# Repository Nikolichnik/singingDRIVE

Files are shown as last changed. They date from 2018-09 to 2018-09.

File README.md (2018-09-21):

# singingDRIVE
<h4>Old CD-ROM drive re purposed to sing.</h4>

It includes stepper motor driver controlled by Arduino microntroller. Video demo available <a href="https://www.youtube.com/watch?v=EQ7sJ51bUXY"><em>here</em></a> or you can just click image below.

<hr>

<p align="center">
  
</p>

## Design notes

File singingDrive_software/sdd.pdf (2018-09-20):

/*
----------------------------------------------------------------------------------------------------------------------------Ima gomila stimunga koji treba tek da se klasifikuje i upakuje kako treba- bude li potrebe. :P
Definisane vrednosti za note su cesto tweakovane da bi se postigao neki efekat u nekim deonicama- ima
dosta odstupanja od zadatih vrednosti. Osnova za navedene zadate vrednosti je u tabeli ispod:

vr. note I vr. u f-ji
cela | I | 4
pola | I | 2
cetvrtinaI | 1
osmina I | 0.5
1/16 | I | 0.25
1/32 | I | 0.125
1/64 | I | 0.0625

----------------------------------------------------------------------------------------------------------------------------*/

int coila1 = 4;
int coila2 = 5;
int coilb1 = 6;
int coilb2 = 7;
int sensor = 11;

int LEDb = 13;
int LEDc = 10;
float tempo = 99.00; | // Tempo, bpm.
float t = (60.00/tempo)/8; | // Trajanje cele note u sekundama/8
int o = 1; // Za podizanje oktave.
float H0 = o*30.87;
float C1 = o*32.70;
float C1s = o*34.65;
float D1 = o*36.71;
float D1s = o*38.89;
float E1 = o*41.20;
float F1 = o*43.65;
float F1s = o*46.25;
float G1 = o*49.00;
float G1s = o*51.91;
float lA1 = o*55.00; | // Zbog postojeih promenljivih za analogne pinove.
float A1s = o*58.27;
float H1 = o*61.74;
float C2 = o*65.41;
float C2s = o*69.30;
float D2 = o*73.42;
float D2s = o*77.80;
float E2 = o*82.41;
float F2 = o*87.31;
float F2s = o*92.50;
float G2 = o*98.00;
float G2s = o*103.83;
float lA2 = o*110.00; | // Zbog postojeih promenljivih za analogne pinove.
float A2s = o*116.54;
float H2 = o*123.47;
float C3 = o*130.81;
float C3s = o*138.59;
float D3 = o*146.83;
float D3s = o*155.56;
float E3 = o*164.81;
float F3 = o*179.61;
float F3s = o*185.00;
float G3 = o*199.9999;
float G3s = o*207.65;
float lA3 = o*220.00; | // Zbog postojeih promenljivih za analogne pinove.
float A3s = o*233.08;
float H3 = o*246.94;
float C4 = o*261.63;

void setup() {

pinMode(coila1, OUTPUT);
pinMode(coila2, OUTPUT);
pinMode(coilb1, OUTPUT);
pinMode(coilb2, OUTPUT);
pinMode(sensor, INPUT);
pinMode(LEDb, OUTPUT);
pinMode(LEDc, OUTPUT);

Serial.begin(115200);

}

void loop() {

float cela = 4;
float pola = 2;
float cetvrtina = 1;
float osmina = 0.5;
float sesnaestina = 0.25;
float tripola = 0.125;
float sestcetvrt = 0.0625;
float dvanaestosam = 0.03125;
float p = (t*1000.0)/8; | // Vrednost cele pauze, t je trajanje cele note u sekundama/8, za delay funkciju nam trebaju milisekunde.
int sensor_state;

sensor_state = digitalRead(sensor);

if(sensor_state == LOW) { | // Kako bismo vratili šeta✁a na po✁etak pre svake ponovljene sekvence.

play(C4, 0.01, 0);

}

else {

//-----------------------------------------------------------------------------------------------------------------------------------------------------------------------

delay(900);

play(C3, 1, 1);
delay(p*0.75);
play(C3, 0.5, 1);
play(C3, 0.165, 1);
play(C3, 0.165, 0);
play(C3, 0.165, 1);
play(C3, 0.5, 0);
play(C3, 0.165, 0);
play(C3, 0.165, 1);
play(C3, 0.165, 0);
play(G2s, 0.165, 1);
play(G2s, 0.165, 0);
play(G2s, 0.165, 1);
play(G2s, 0.5, 1);
delay(p);

play(C3, 1, 1);
delay(p*0.75);
play(C3, 0.5, 1);
play(C3, 0.165, 1);
play(C3, 0.165, 0);
play(C3, 0.165, 1);
play(C3, 0.5, 0);
play(C3, 0.165, 0);
play(C3, 0.165, 0);
play(C3, 0.165, 0);
play(G2s, 0.165, 1);
play(G2s, 0.165, 0);
play(G2s, 0.165, 1);
play(G2s, 0.5, 1);
delay(p);

play(C3, 1, 1);
delay(p*0.75);
play(C3, 0.5, 0);
play(C3, 0.165, 1);
play(C3, 0.165, 0);
play(C3, 0.165, 1);
play(C3, 0.5, 0);
play(C3, 0.165, 0);
play(C3, 0.165, 0);
play(C3, 0.165, 0);
play(G2s, 0.165, 1);
play(G2s, 0.165, 1);
play(G2s, 0.165, 1);
play(G2s, 0.5, 1);
delay(p);

play(C2, 1.1, 0);
play(C2, 1.1, 0);
play(C2, 1.1, 0);
play(G1s, 0.75, 1);
play(D2s, 0.33, 0);
play(C2, 1.1, 1);
play(G1s, 0.75, 1);
play(D2s, 0.33, 0);
play(C2, 2, 0);
play(G2, 1.1, 0);
play(G2, 1.1, 1);
play(G2, 1.1, 0);
play(G2s, 0.75, 1);
play(D2s, 0.33, 0);
play(C2, 1.1, 1);
play(G1s, 0.75, 1);
play(D2s, 0.33, 0);
play(C2, 2, 0);

play(C3, 1.1, 1);
play(C2, 0.75, 0);
play(C2, 0.25, 1);
play(C3, 1.1, 1);
play(H2, 0.75, 0);
play(A2s, 0.25, 1);
play(lA2, 0.25, 0);
play(G2s, 0.25, 1);
play(lA2, 0.5, 0);
delay(p*32);
play(C2s, 0.45, 1);
delay(p*0.25);
play(F2s, 1.1, 0);
play(F2, 0.75, 1);
play(E2, 0.25, 0);
play(D2s, 0.25, 1);
play(D2, 0.25, 0);
play(D2s, 0.5, 1);
delay(p*32);
play(G1s, 0.45, 1);
play(H1, 1.1, 1);
play(G1s, 0.75, 1);
delay(p*0.25);
play(H1, 0.25, 0);
play(D2s, 1.1, 0);
play(C2, 0.75, 1);
delay(p*0.25);
play(D2s, 0.25, 0);
play(G2, 2.2, 0);

play(C3, 1.1, 1);
play(C2, 0.75, 0);
play(C2, 0.25, 1);
play(C3, 1.1, 1);
play(H2, 0.75, 0);
play(A2s, 0.25, 1);
play(lA2, 0.25, 0);
play(G2s, 0.25, 1);
play(lA2, 0.5, 0);
delay(p*32);
play(C2s, 0.45, 1);

play(F2s, 1.1, 0);
play(F2, 0.75, 1);
play(E2, 0.25, 0);

play(D2s, 0.25, 1);
play(D2, 0.25, 0);
play(D2s, 0.5, 1);
delay(p*32);
play(G1s, 0.45, 1);
play(H1, 1.1, 1);
play(G1s, 0.75, 1);

play(H1, 0.25, 0);
play(D2s, 1.1, 0);
play(G1s, 0.75, 1);
delay(p*0.25);
play(C2, 0.25, 0);
play(C2, 2.5, 0);
delay(p*0.5);

play(C3, 1, 1);
delay(p*0.5);
play(C3, 0.5, 1);
play(C3, 0.165, 1);
play(C3, 0.165, 0);
play(C3, 0.165, 1);
play(C3, 0.5, 0);
play(C3, 0.165, 0);
play(C3, 0.165, 1);
play(C3, 0.165, 0);
play(G2s, 0.165, 1);
play(G2s, 0.165, 0);
play(G2s, 0.165, 1);
play(G2s, 0.5, 1);
delay(p);

play(C3, 1, 1);
delay(p*0.75);
play(C3, 0.5, 1);
play(C3, 0.165, 1);
play(C3, 0.165, 0);
play(C3, 0.165, 1);
play(C3, 0.5, 0);
play(C3, 0.165, 0);
play(C3, 0.165, 1);
play(C3, 0.165, 0);
play(G2s, 0.165, 1);
play(G2s, 0.165, 0);
play(G2s, 0.165, 1);
play(G2s, 0.5, 1);
delay(p);

play(C3, 1, 1);
delay(p*0.75);
play(C3, 0.5, 1);
play(C3, 0.165, 0);
play(C3, 0.165, 0);
play(C3, 0.165, 1);
play(C3, 0.5, 0);
play(C3, 0.165, 0);
play(C3, 0.165, 1);
play(C3, 0.165, 0);
play(G2s, 0.165, 1);
play(G2s, 0.165, 0);
play(G2s, 0.165, 1);
play(G2s, 0.5, 0);

play(G2, 0.5, 0);
play(G2, 0.165, 0);
play(G2, 0.165, 0);
play(G2, 0.165, 0);

play(G2s, 0.165, 0);
play(G2s, 0.165, 0);
play(G2s, 0.165, 0);
play(A2s, 0.5, 0);

play(C3, 0.5, 0);
play(C3, 0.165, 0);
play(C3, 0.165, 0);
play(C3, 0.165, 0);
play(C3s, 0.165, 1);
play(C3s, 0.165, 0);
play(C3s, 0.165, 1);
play(F3, 0.5, 0);

delay(p*256);

/*
play(D2, 2.2, 1);
delay(p*2.2);
play(D2, 2.2, 1);
delay(p*2.2);
play(D2, 2.2, 1);
delay(p*2.2);
play(D2, 2.2, 1);
delay(p*2.2);
play(D2, 2.2, 0);
delay(p*2.2);
play(D2, 2.2, 0);
delay(p*2.2);
play(D2, 2.2, 0);
delay(p*2.2);
play(D2, 2.2, 0);
delay(p*2.2);
*/
//------------------------------------------------------------------------------------------------------------------------------------------------------------------

play(C2, 1.5, 1);
play(C2, 0.25, 1);

play(C2, 1.5, 1);

play(C2, 1, 1);
play(C2, 1, 1);
play(C2, 0.5, 0);

play(C2, 0.33, 0);
play(C2, 0.33, 1);
play(C2, 0.33, 0);

play(E2, 1.5, 1);

play(E2, 1.5, 0);

play(C2, 0.25, 0);
play(E2, 1, 1);
play(E2, 1, 0);
play(E2, 0.5, 1);
play(E2, 0.5, 0);
play(E2, 0.33, 1);
play(C2, 0.33, 0);
play(E2, 0.33, 1);

play(G2, 1.5, 1);
play(E2, 0.25, 1);
play(E2, 0.25, 0);
play(G2, 1.5, 0);
play(E2, 0.25, 1);
play(E2, 0.25, 0);
play(G2, 1, 1);
play(G2, 1, 0);
play(G2, 0.5, 1);
play(G2, 0.5, 0);
play(G2, 0.33, 1);
play(E2, 0.33, 0);
play(G2, 0.33, 1);

play(lA2, 2.5, 0);
delay(p*0.5);
play(lA2, 0.33, 1);
play(lA2, 0.33, 0);
play(lA2, 0.33, 1);
play(H2, 1.5, 1);
play(C3, 0.1875, 0);
play(H3, 0.1875, 0);
play(lA3, 0.1875, 0);
play(G3, 0.1875, 0);
play(C3, 0.1875, 1);
play(H3, 0.1875, 1);
play(lA3, 0.1875, 1);
play(G3, 0.1875, 1);
play(C3, 1, 0);
play(C3, 0.33, 1);
play(C3, 0.33, 0);
play(C3, 0.33, 1);
play(C3, 0.5, 0);
delay(p*32);

play(C2, 0.75, 1);
play(C2, 0.25, 1);
play(F2, 2, 1);
play(G2, 1.35, 1);
play(G2s, 0.33, 0);
play(A2s, 0.33, 1);
play(G2s, 2, 0);
play(C2, 1.1, 1);
delay(p*0.5);

play(C2, 0.5, 1);
play(C2, 0.5, 0);
play(F2, 1.7, 1);
play(G2, 0.5, 1);
play(G2s, 0.5, 0);
play(C2, 0.5, 1);
play(lA2, 0.33, 0);
play(F2, 0.33, 1);
play(C3, 0.33, 0);
play(A2s, 3, 0);

play(C2, 0.75, 1);
play(C2, 0.25, 1);
play(F2, 1.75, 0);
play(G2, 0.25, 1);
play(G2s, 0.75, 1);
play(F2, 0.25, 1);
play(C3, 0.75, 1);
play(lA2, 0.25, 1);
play(F3, 2, 0);
play(F2, 1, 0);

play(G2s, 0.33, 1);
play(G2, 0.33, 0);
play(F2, 0.33, 1);
play(C3, 1.33, 1);
play(G2s, 0.33, 0);
play(F2, 0.33, 0);
play(C2, 1, 1);
play(C2, 0.75, 0);
play(C2, 0.25, 1);
play(F2, 2.5, 1);
delay(p*0.5);

play(C2, 0.75, 1);
play(C2, 0.25, 1);
play(F2, 2, 0);
play(G2, 1.35, 1);
play(G2s, 0.33, 0);
play(A2s, 0.33, 1);
play(G2s, 2, 0);
play(C2, 1.1, 1);

play(F2, 1.7, 0);
play(G2, 0.5, 1);
play(G2s, 0.5, 0);

play(lA2, 0.33, 0);
play(F2, 0.33, 1);
play(C3, 0.33, 0);
play(A2s, 3, 1);

play(C2, 0.75, 1);

play(F2, 1.75, 0);
play(G2, 0.25, 1);
play(G2s, 0.75, 0);
play(F2, 0.25, 1);
play(C3, 0.75, 0);
play(lA2, 0.25, 1);
play(F3, 2, 0);
play(F2, 1, 1);

play(G2s, 0.33, 1);
play(G2, 0.33, 0);
play(F2, 0.33, 1);
play(C3, 1.33, 1);
play(G2s, 0.33, 0);
play(F2, 0.33, 0);
play(C2, 1, 1);
play(C2, 0.75, 0);
play(C2, 0.25, 1);
play(F2, 2.5, 0);
delay(p*0.41);

play(F2, 1.5, 1);
play(F2, 0.25, 1);
play(F2, 0.25, 0);
play(F2, 1.5, 1);
play(F2, 0.25, 0);
play(F2, 0.25, 0);
play(F2, 1, 1);
play(F2, 1, 1);
play(F2, 0.5, 0);
play(F2, 0.5, 1);
play(F2, 0.33, 0);
play(F2, 0.33, 1);
play(F2, 0.33, 0);

play(lA2, 1.5, 1);
play(lA2, 0.25, 0);
play(lA2, 0.25, 0);
play(lA2, 1.5, 1);
play(lA2, 0.25, 0);
play(lA2, 0.25, 1);
play(D3, 1, 0);
play(D3, 1, 1);
play(D3, 0.5, 0);
play(D3, 0.5, 1);
play(D3, 0.33, 0);
play(D3, 0.33, 1);
play(D3, 0.33, 0);

play(E3, 1.5, 0);
delay(p*0.25);
play(C3, 0.1875, 1);
play(H3, 0.1875, 0);
play(lA3, 0.1875, 1);
play(G3, 0.1875, 1);
play(C3, 0.1875, 0);
play(H3, 0.1875, 1);
play(lA3, 0.1875, 0);
play(G3, 0.1875, 1);
play(C3, 1, 1);
play(C3, 0.33, 0);
play(C3, 0.33, 1);
play(C3, 0.33, 0);
play(C3, 1, 1);

//-----------------------------------------------------------------------------------------------------------------------------------------------------------------------

delay(900);

}

}

void play(float f, float v, int s) { | // (frekvencija, vrednost, smer (bilo sta vece od 0 (koristim 1 uglavnom) je napred, 0 nazad))

int i;
float h;
float d; | // duration
float p = (t*1000.0)/8; | // vrednost cele pauze, t je trajanje cele note u sekundama/8, za delay funkciju nam trebaju milisekunde.
h = (1000.0)/f; | // koliko puta u 1000ms je frekvencija f, iz toga sledi h- period.
d = (v*f*t); | // vrednost note ponovljene frekvencija puta (to je za trajanje od jedne sekunde) pomnožena sa t.
| // Za t=1 imam 60bpm- 60 nota u minuti.

if (s>0) {

for (i = 0; i <= d; i++) {

digitalWrite(LEDb, HIGH);

digitalWrite(coila1, HIGH); digitalWrite(coila2, LOW); digitalWrite(coilb1, LOW); digitalWrite(coilb2, HIGH); delay(h);

digitalWrite(coila1, HIGH); digitalWrite(coila2, LOW); digitalWrite(coilb1, HIGH); digitalWrite(coilb2, LOW); delay(h);

digitalWrite(coila1, LOW); digitalWrite(coila2, HIGH); digitalWrite(coilb1, HIGH);

digitalWrite(coilb2, LOW); delay(h);

digitalWrite(coila1, LOW); digitalWrite(coila2, HIGH); digitalWrite(coilb1, LOW); digitalWrite(coilb2, HIGH); delay(h);

digitalWrite(LEDb, LOW);

}

}

else {

for (i = 0; i <= d; i++) {

digitalWrite(LEDc, HIGH);

digitalWrite(coila1, LOW); | // Sekvenca u nazad- imajui u vidu koji je bio poslednji korak ranije, eksperimentisati sa ovim.
digitalWrite(coila2, HIGH);
digitalWrite(coilb1, HIGH);
digitalWrite(coilb2, LOW);
delay(h);

digitalWrite(coila1, HIGH); digitalWrite(coila2, LOW); digitalWrite(coilb1, HIGH); digitalWrite(coilb2, LOW); delay(h);

digitalWrite(coila1, HIGH); digitalWrite(coila2, LOW); digitalWrite(coilb1, LOW); digitalWrite(coilb2, HIGH); delay(h);

digitalWrite(coila1, LOW); digitalWrite(coila2, HIGH); digitalWrite(coilb1, LOW); digitalWrite(coilb2, HIGH); delay(h);

digitalWrite(LEDc, LOW);

}

}

delay(p*v*21); | // Pauza nakon svake note, definisana trajanjem note. Pomaze u postizanju staccato osecaja i uopste boljoj
definiciji note.

Serial.print("Frekvencija: ");
Serial.print(f);
Serial.print(" _____ Period: "); Serial.print(h);
Serial.print(" _____ Broj ponavljanja: "); Serial.println(d);

}

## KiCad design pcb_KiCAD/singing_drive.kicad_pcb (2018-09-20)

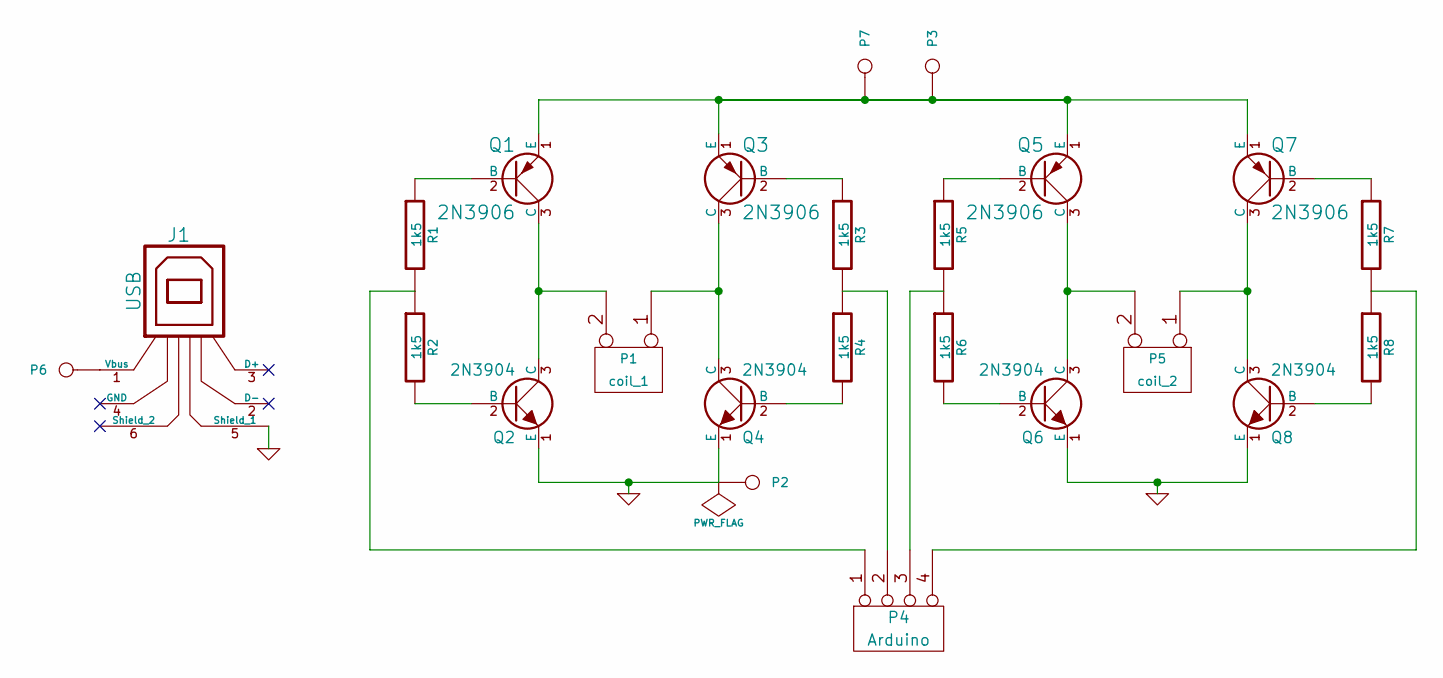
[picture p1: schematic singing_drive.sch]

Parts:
J1: USB
P1: coil_1
P2, P3, P6, P7: CONN_1
P4: Arduino
P5: coil_2
Q1, Q3, Q5, Q7: 2N3906
Q2, Q4, Q6, Q8: 2N3904
R1, R2, R3, R4, R5, R6, R7, R8: 1k5

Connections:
GND: J1.5 (Shield_1), P2.1, Q2.1 (E), Q4.1 (E), Q6.1 (E), Q8.1 (E)
unnamed: P4.1, R1.2, R2.1
unnamed: P4.4, R7.2, R8.1
unnamed: P4.3, R5.2, R6.1
unnamed: P4.2, R3.2, R4.1
unnamed: Q8.2 (B), R8.2
unnamed: Q7.2 (B), R7.1
unnamed: P5.1, Q7.3 (C), Q8.3 (C)
unnamed: P5.2 (PM), Q5.3 (C), Q6.3 (C)
unnamed: Q5.2 (B), R5.1
unnamed: Q6.2 (B), R6.2
unnamed: J1.1 (Vbus), P6.1
unnamed: P3.1, P7.1, Q1.1 (E), Q3.1 (E), Q5.1 (E), Q7.1 (E)
unnamed: Q1.2 (B), R1.1
unnamed: Q2.2 (B), R2.2
unnamed: P1.2 (PM), Q1.3 (C), Q2.3 (C)
unnamed: Q4.2 (B), R4.2
unnamed: Q3.2 (B), R3.1
unnamed: P1.1, Q3.3 (C), Q4.3 (C)

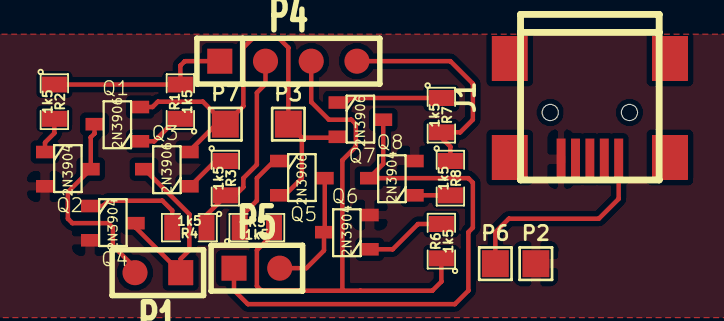
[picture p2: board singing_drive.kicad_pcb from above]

Board: 2 copper layers, 24 parts (0 on the bottom side), 19 nets.
